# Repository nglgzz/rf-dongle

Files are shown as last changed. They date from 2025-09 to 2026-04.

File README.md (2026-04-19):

# RF Dongle

USB type-A dongle based on the nRF52840 microcontroller.

This dongle is meant to run the [COB firmware](https://github.com/nglgzz/cob_firmware),
though technically you can flash whatever you want on it.

## Current state

**What works**

- The dongle can be programmed through the SWD pads exposed on the back of the
  PCB.
- Debugging the microcontroller while it runs also works, through the same SWD
  pads.
- LEDs and reset buttons work.
- The chip antenna works and has a good range. I haven't tested its limit, but I
  tried both sending and receiving packets across a room (5-ish meters with a
  wall in between) and it worked fine and that's more than enough for my
  application.
- USB power is working, the device gets detected by the host, and it can
  enumerate as a HID device (haven't tried other USB 2.0 classes, but they
  should in theory work).

**What needs improvement**

- The USB connector (PCB trace) is quite thin, and in some USB ports it doesn't
  make a solid connection. One workaround is to add some tape on the underside
  of the PCB to increase its thickness. Need to figure out a neater solution
  though.

## Pics

This is the manufactured PCB (at [this commit](https://github.com/nglgzz/rf-dongle/tree/d430271ced6d7d4ebfe34358b9420bd28b8e23bf)).
The component pads are designed to make it easier to hand solder the components,
which is what I did.

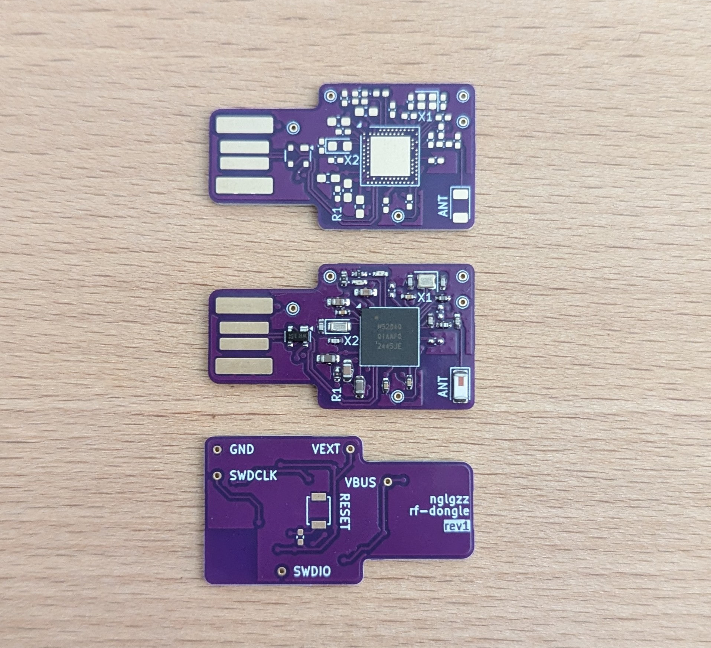
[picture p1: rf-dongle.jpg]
picture of manufactured PCBs
<br/>

Below is the test jig I'm using to program and debug the dongle. I hacked this
together with a perforated board, a few pogo pins, and battery connectors I had
lying around.

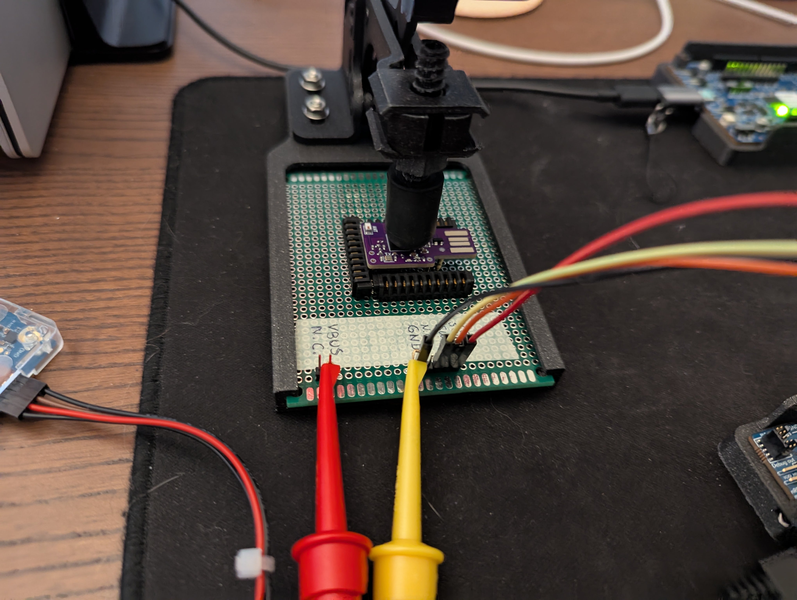
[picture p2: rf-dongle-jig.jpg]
picture of testing jig for assembled rf-dongle
<br/>

## Contributing

If you (unlike me) know what you're doing, and have tips for my circuit design,
please create an issue and tell me about it 🙏

## Learning

If you're curious about my learning journey with this project, I've documented
that [here](./LEARNING.md).

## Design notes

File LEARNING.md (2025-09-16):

# [RF Dongle](./README.md) - Learning

The purpose of this file is to document my learning journey with
this project.

Following is a brief description of what my relevant knowledge
was before starting this project, and a list of resources I found
most useful to fill missing gaps and make progress on it.

## Starting point

Going into this project, I was familiar with fundamentals of
electronics, I was somewhat comfortable reading schematics, though
certain components were still a mystery to me (e.g. capacitors
and inductors).

I have also designed a handful of simple PCBs for custom
keyboards. These PCBs had 2 layers, and mostly use through
hole components that I assembled manually, and the components
include a development board used as a module plus mechanical
switches and diodes.

During the design of these boards I never really thought about
manufacturability, nor signal integrity, and when routing traces
there was not much thought process, besides following the
schematic and trying to make the end result look aesthetically
pleasing.

## Components

- [Decoupling capacitors - Simply put](https://www.youtube.com/watch?v=BpuCv4hfYZU)

- [Inductors and capacitors in-depth](https://www.youtube.com/watch?v=r1t0ZjD9X7A)

## Signal integrity

- [How to achieve proper grouding - Rick Hartley](https://www.youtube.com/watch?v=ySuUZEjARPY)
  Current flows in fields, not in wires. This talk helped
  building an intuition for how to route trace and place
  components to minimize interference.

## PCB / Chip Antenna

- [PCB Antenna - How to design, measure and tune](https://www.youtube.com/watch?v=x1m8G8MAeUQ)
  Goes through things to keep in mind when designing a PCB
  antenna, it explains the purpose of a matching network,
  and demonstrates the measuring and tuning of the antenna
  through changing component values in the matching network.
  A lot of antenna related concepts started clicking only
  after watching this video.

- [How to correctly place a chip antenna on your PCB](https://www.youtube.com/watch?v=F6iBKXAfC5Q)
  More design considerations for antennas, but in this case it's
  specific to chip antennas (vs. PCB antennas). These
  considerations are demonstrated with simulations.

- [Why is 50 Ohm impedance used in PCB layout](https://www.youtube.com/watch?v=4OBO760u7jg)
  Interesting explanation on why the target impedance for
  circuits is usually 50 Ohms.

- [How to design a PCB with an antenna](https://www.youtube.com/watch?v=e0eY1L77A-E)
  Summarizes the process of calculating the parameters for
  a controlled impedance line to be used as a feed for
  an antenna.

## PCB Layout

- [Your BGA and you](https://www.youtube.com/watch?v=NTrP3fDrViQ)
  Design and manufacturing considerations for the fanout of a
  ball grid array (BGA) package.

- [When to use via in pad](https://www.youtube.com/watch?v=-L-0CkH3aEk)
  Design and manufacturing considerations for using via in pad
  (instead of dog bone fanout).

- [KiCad 6 STM32 PCB Design full tutorial](https://www.youtube.com/watch?v=aVUqaB0IMh4)
  Complete walkthrough of designing a board that uses an STM32
  microcontroller, with KiCad. Really useful to get an idea of
  the workflow.

## Other

- [JLC PCB capabilities](https://jlcpcb.com/capabilities/pcb-capabilities)
  Manufacturing capabilities of JLCPCB, which I chose as the
  PCB manufacturer for this project. These capabilities paired
  with trying out different options in the quote section
  (and seeing how the changes impacted price) heavily influenced
  the final design.

- [nRF52840 Reference circuit no. 1 for QIAA aQFN73](https://docs.nordicsemi.com/bundle/ps_nrf52840/page/ref_circuitry.html#ariaid-title2)
  Reference circuit for the nRF52840 in the QIAA layout, which
  was the cheaper layout to manufacture (compared to the BGA
  version). no. 1 refers to the configuration where the
  microcontroller is powered via USB. The downloadable reference
  for the PCB layout was also super useful.

- nRF52840-DK and nRF52840-Dongle: these are the development
  boards for the nRF52840. When in doubt on where to place
  something, or what kind of components were used, I checked
  these boards for answers, while crossreferencing with the
  reference circuit from the datasheet.

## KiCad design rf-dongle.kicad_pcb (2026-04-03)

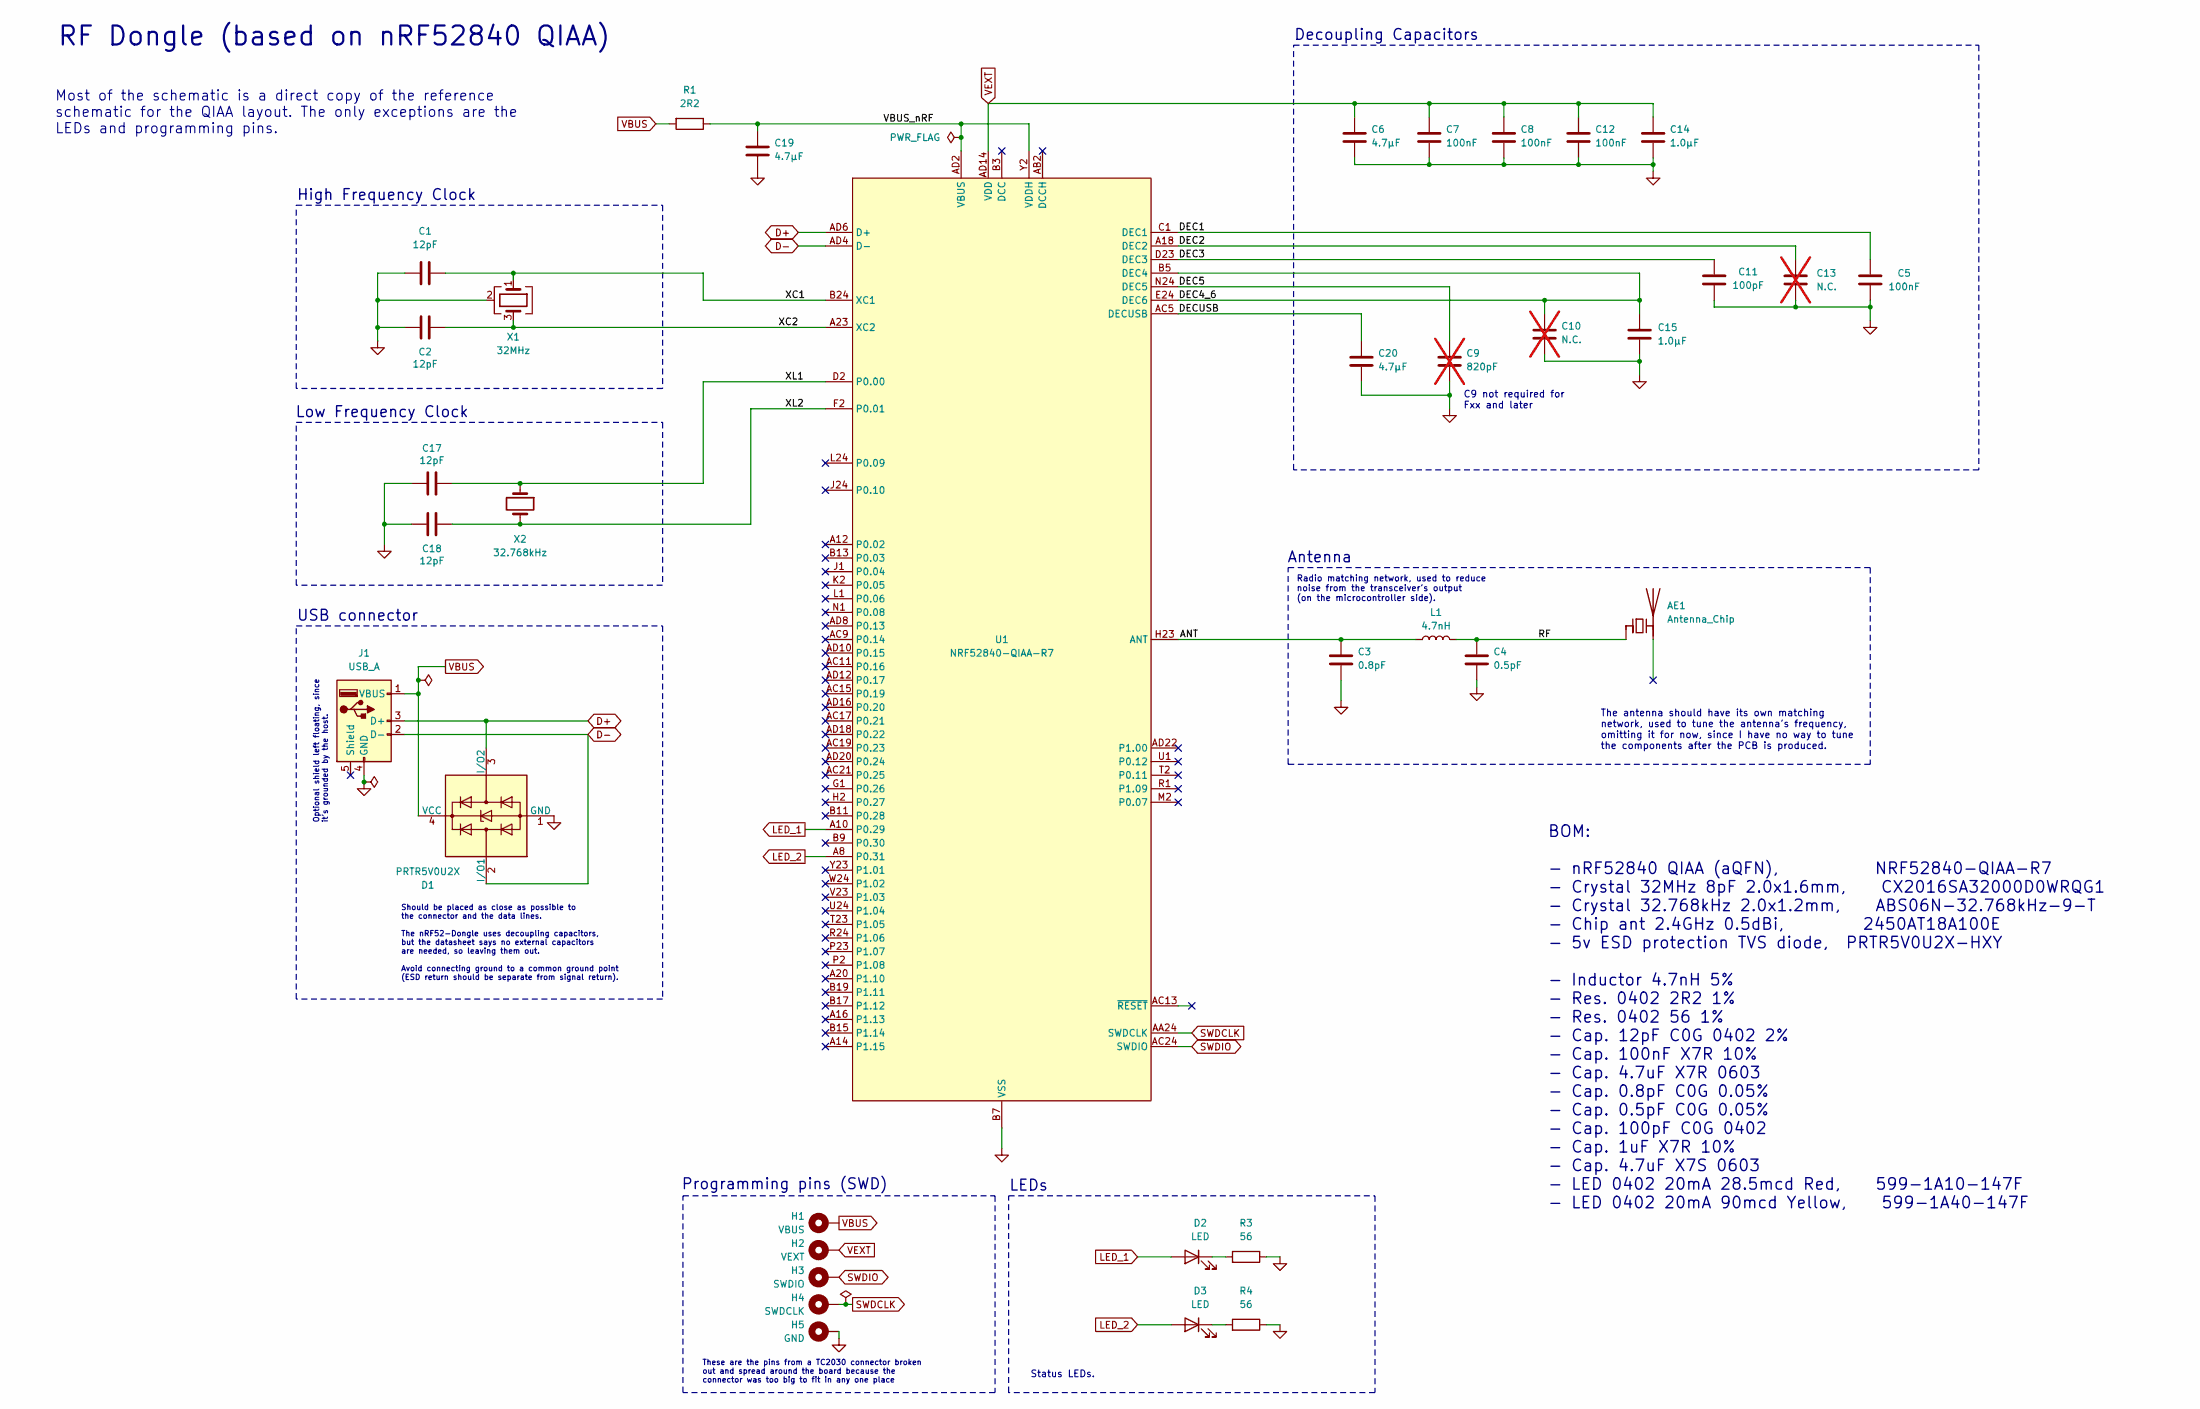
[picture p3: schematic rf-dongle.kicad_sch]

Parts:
AE1: Antenna_Chip; Johanson_2450AT18x100; JLC PN C89334
C1, C2, C17, C18: 12pF; C_0402_1005Metric_Pad0.74x0.62mm_HandSolder
C3: 0.8pF; C_0402_1005Metric_Pad0.74x0.62mm_HandSolder
C4: 0.5pF; C_0402_1005Metric_Pad0.74x0.62mm_HandSolder
C5, C7, C8, C12: 100nF; C_0402_1005Metric_Pad0.74x0.62mm_HandSolder
C6, C19, C20: 4.7µF; C_0603_1608Metric_Pad1.08x0.95mm_HandSolder
C9: 820pF; C_0402_1005Metric_Pad0.74x0.62mm_HandSolder; not fitted
C10, C13: N.C.; C_0402_1005Metric_Pad0.74x0.62mm_HandSolder; not fitted
C11: 100pF; C_0402_1005Metric_Pad0.74x0.62mm_HandSolder
C14, C15: 1.0µF; C_0603_1608Metric_Pad1.08x0.95mm_HandSolder
D1: PRTR5V0U2X; SOT-143; JLC PN C5337179
D2: LED; LED_0402_1005Metric_Pad0.77x0.64mm_HandSolder; JLC PN C165980
D3: LED; LED_0402_1005Metric_Pad0.77x0.64mm_HandSolder; JLC PN C165979
H1: VBUS; TestPoint_THTPad_D1.0mm_Drill0.5mm
H2: VEXT; TestPoint_THTPad_D1.0mm_Drill0.5mm
H3: SWDIO; TestPoint_THTPad_D1.0mm_Drill0.5mm
H4: SWDCLK; TestPoint_THTPad_D1.0mm_Drill0.5mm
H5: GND; TestPoint_THTPad_D1.0mm_Drill0.5mm
J1: USB_A; PCB_USB_connector
L1: 4.7nH; L_0402_1005Metric_Pad0.77x0.64mm_HandSolder
R1: 2R2; R_0402_1005Metric_Pad0.72x0.64mm_HandSolder
R3, R4: 56; R_0402_1005Metric_Pad0.72x0.64mm_HandSolder; JLC PN C784160
U1: NRF52840-QIAA-R7; Nordic_AQFN-73-1EP_7x7mm_P0.5mm; JLC PN C1851953
X1: 32MHz; Crystal_SMD_2016-4Pin_2.0x1.6mm
X2: 32.768kHz; Crystal_SMD_2012-2Pin_2.0x1.2mm_HandSoldering; JLC PN C97603

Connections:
/ANT: C3.2, L1.1, U1.H23 (ANT)
/DEC1: C5.1, U1.C1 (DEC1)
/DEC2: C13.1, U1.A18 (DEC2)
/DEC3: C11.1, U1.D23 (DEC3)
/DEC4_6: C10.2, C15.2, U1.B5 (DEC4), U1.E24 (DEC6)
/DEC5: C9.2, U1.N24 (DEC5)
/DECUSB: C20.2, U1.AC5 (DECUSB)
/RF: AE1.1 (FEED), C4.2, L1.2
/VBUS_nRF: C19.2, R1.1, U1.AD2 (VBUS), U1.Y2 (VDDH)
/XC1: C1.2, U1.B24 (XC1), X1.1
/XC2: C2.1, U1.A23 (XC2), X1.3
/XL1: C17.2, U1.D2 (P0.00), X2.1
/XL2: C18.1, U1.F2 (P0.01), X2.2
D+: D1.3 (I/O2), J1.3 (D+), U1.AD6 (D+)
D-: D1.2 (I/O1), J1.2 (D-), U1.AD4 (D-)
GND: C1.1, C2.2, C3.1, C4.1, C5.2, C6.1, C7.1, C8.1, C9.1, C10.1, C11.2, C12.1, C13.2, C14.1, C15.1, C17.1, C18.2, C19.1, C20.1, D1.1 (GND), H5.1, J1.4 (GND), R3.1, R4.1, U1.B7 (VSS), U1.EP (VSS), U1.F23 (VSS_PA), X1.2 (G), X1.4 (G)
LED_1: D2.2 (A), U1.A10 (P0.29)
LED_2: D3.2 (A), U1.A8 (P0.31)
unnamed: D2.1 (K), R3.2
unnamed: D3.1 (K), R4.2
SWDCLK: H4.1, U1.AA24 (SWDCLK)
SWDIO: H3.1, U1.AC24 (SWDIO)
VBUS: D1.4 (VCC), H1.1, J1.1 (VBUS), R1.2
VEXT: C6.2, C7.2, C8.2, C12.2, C14.2, H2.1, U1.A22 (VDD), U1.AD14 (VDD), U1.AD23 (VDD), U1.B1 (VDD), U1.W1 (VDD)

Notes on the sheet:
Antenna
RF Dongle (based on nRF52840 QIAA)
Decoupling Capacitors
LEDs
Radio matching network, used to reduce noise from the transceiver's output (on the microcontroller side).
Status LEDs.
C9 not required for Fxx and later
The antenna should have its own matching network, used to tune the antenna's frequency, omitting it for now, since I have no way to tune the components after the PCB is produced.
BOM: - nRF52840 QIAA (aQFN), NRF52840-QIAA-R7 - Crystal 32MHz 8pF 2.0x1.6mm, CX2016SA32000D0WRQG1 - Crystal 32.768kHz 2.0x1.2mm, ABS06N-32.768kHz-9-T - Chip ant 2.4GHz 0.5dBi, 2450AT18A100E - 5v ESD protection TVS diode, PRTR5V0U2X-HXY - Inductor 4.7nH 5% - Res. 0402 2R2 1% - Res. 0402 56 1% - Cap.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
Low Frequency Clock
USB connector
These are the pins from a TC2030 connector broken out and spread around the board because the connector was too big to fit in any one place
Optional shield left floating, since it's grounded by the host.
Most of the schematic is a direct copy of the reference schematic for the QIAA layout. The only exceptions are the LEDs and programming pins.
Should be placed as close as possible to the connector and the data lines. The nRF52-Dongle uses decoupling capacitors, but the datasheet says no external capacitors are needed, so leaving them out. Avoid connecting ground to a common ground point (ESD return should be separate from signal return).
Programming pins (SWD)
High Frequency Clock

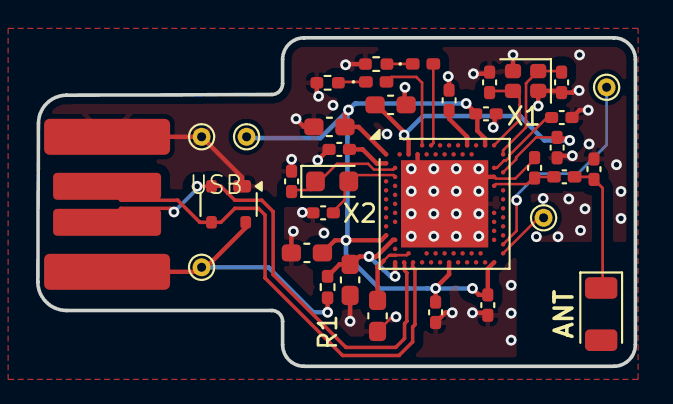
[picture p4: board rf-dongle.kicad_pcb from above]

Board: 4 copper layers, 33.2 x 18.2 mm, 35 parts (0 on the bottom side), 23 nets.

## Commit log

2025-07-21 add first draft of schematic
    [rf-dongle.kicad_sch]
2025-07-21 add rough pcb layout
    [rf-dongle.kicad_pcb, rf-dongle.kicad_sch]
2025-07-21 setup pcb stackup
    [rf-dongle.kicad_pcb, rf-dongle.kicad_sch]
2025-07-21 setup constraints, first attempt at routing
    [rf-dongle.kicad_pcb, rf-dongle.kicad_sch]
2025-07-21 second attempt at routing
    [rf-dongle.kicad_pcb, rf-dongle.kicad_sch]
2025-07-21 add jobset
    [rf-dongle.kicad_pcb]
2025-07-21 before new programming pins
    [rf-dongle.kicad_pcb, rf-dongle.kicad_sch]
2025-07-21 rework programming pins, cleanup pcb routing
    [rf-dongle.kicad_pcb, rf-dongle.kicad_sch]
2025-07-21 adjust footprints for handsoldering, tweak antenna
    [rf-dongle.kicad_pcb, rf-dongle.kicad_sch]
2025-07-21 adjust silkscreen
    [rf-dongle.kicad_pcb]
2025-07-21 ordered rev 1
    [rf-dongle.kicad_pcb]
2025-07-29 update product numbers and bom
    [rf-dongle.kicad_sch]
2025-09-21 cleanup USB routing, add JTAG contacts
    also remove unused components and swap reset button for programmable button
    [rf-dongle.kicad_pcb, rf-dongle.kicad_sch]
2025-09-21 ordered rev 2
    [rf-dongle.kicad_pcb]
2026-04-03 ordered rev 3
    Reverted PCB outline to first iteration, swapped order of USB pads,
    removed an optional component near the antenna, and moved around
    debug pins to more easily align them with the perforated board
    used to create the programming jig.
    [rf-dongle.kicad_pcb, rf-dongle.kicad_sch]
2026-04-03 remove USB pads from solder paste layer (again)
    [rf-dongle.kicad_pcb]
